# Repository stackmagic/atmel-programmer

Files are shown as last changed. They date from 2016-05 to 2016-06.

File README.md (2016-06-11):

# arduino micro as isp attiny/atmega programmer

a simple pcb with a few sockets to program attiny/atmega microcontrollers from
an arduino micro used as isp programmer

# supported atmel chips

| Microcontroller | |
|---|---|
| ATtiny 24/44/84 | http://www.atmel.com/devices/ATTINY84.aspx |
| ATtiny 25/45/85 | http://www.atmel.com/devices/ATTINY85.aspx |
| ATmega 48/88/168/328 | http://www.atmel.com/devices/ATMEGA328.aspx  |
| ATmega 164/324/644/1284 | http://www.atmel.com/devices/ATMEGA1284.aspx |

# usage

all steps below include the use of the Arduino IDE: https://www.arduino.cc/en/Main/Software (1.6 or higher).

Add the following URLs in `File > Preferences` for the setting `Additionals Boards Manager URLs`:

## ATtiny25/45/85 & ATtiny24/44/84 families:

(Supports only 45/85 & 44/84)

https://raw.githubusercontent.com/damellis/attiny/master/package_damellis_attiny_index.json

## ATmega48/88/168/328 family:

(Supports only 168/328)

https://raw.githubusercontent.com/stackmagic/atmega/master/package_carlosefr_atmega_index.json

Note: Once the PR at https://github.com/carlosefr/atmega/pull/4 is merged, use the official URL: https://raw.githubusercontent.com/carlosefr/atmega/master/package_carlosefr_atmega_index.json)

## ATmega164/324/644/1284 family:

https://mcudude.github.io/MightyCore/package_MCUdude_MightyCore_index.json

If you want to program a `Non-P` version (for example an `ATmega1284` instead of an `ATmega1284p`), you need to open your avrdude.conf and add a Section like below. The non-P versions are essentially the same as the P versions and they can be cloned. The plain 644 is supported out of the box (with avrdude 6.0.1).

```
#------------------------------------------------------------
# ATmega1284
#------------------------------------------------------------

part parent "atmega1284p"
    id               = "m1284";
    desc             = "ATmega1284";
    signature        = 0x1e 0x97 0x06;
  ;

#------------------------------------------------------------
# ATmega324
#------------------------------------------------------------

part parent "m324p"
    id               = "m324";
    desc             = "ATmega324";
    signature        = ???????????????????????;
  ;

#------------------------------------------------------------
# ATmega164
#------------------------------------------------------------

part parent "m164p"
    id               = "m164";
    desc             = "ATmega164";
    signature        = ?????????????????????????
  ;
```

## prepare the programmer

* plug in your arduino micro and connect it to the pc
* start up the arduino IDE
* connect your arduino micro
* open up the programmer sketch: `File > Examples > ArduinoISP`
* change the line `#define RESET SS` to `#define RESET 10`
* select `Tools > Board > Arduino Micro`
* burn the programmer to your Arduino Micro with `File > Upload`
* verify the RDY led is pulsing
* select your micro as programmer `Tools > Programmer > Arduino as ISP`

once this is done, you can program as many chips as you want

## burn it

* plug in the chip to program (make sure there's just 1 chip on the board ;))
* open the sketch to program to the chip
* select the correct target board through `Tools > Board > ...`
* burn the sketch using `File > Upload using Programmer`
* the PRG led should light while the program is written
* you're done!

# kicad screenshots

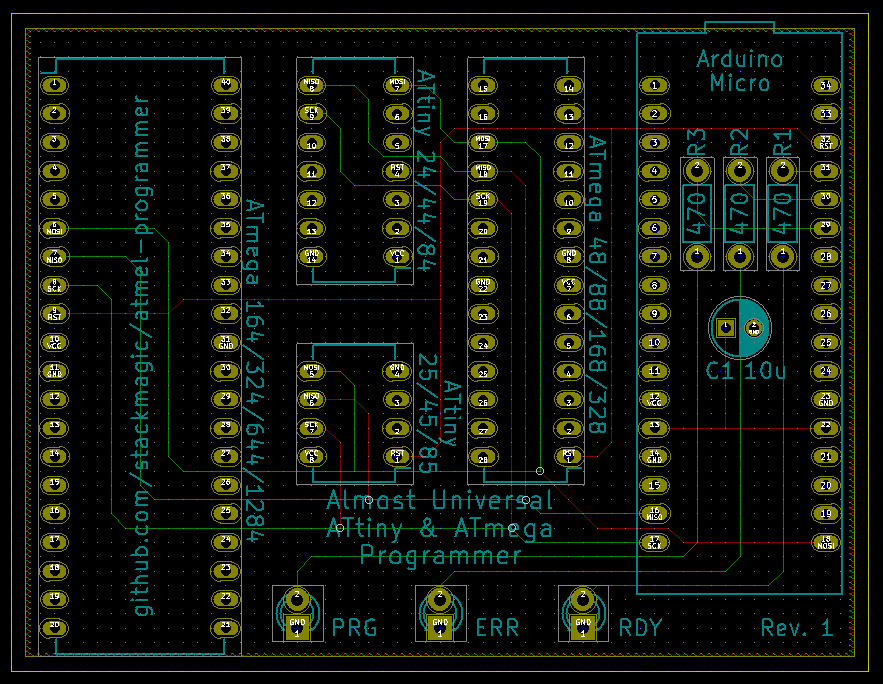
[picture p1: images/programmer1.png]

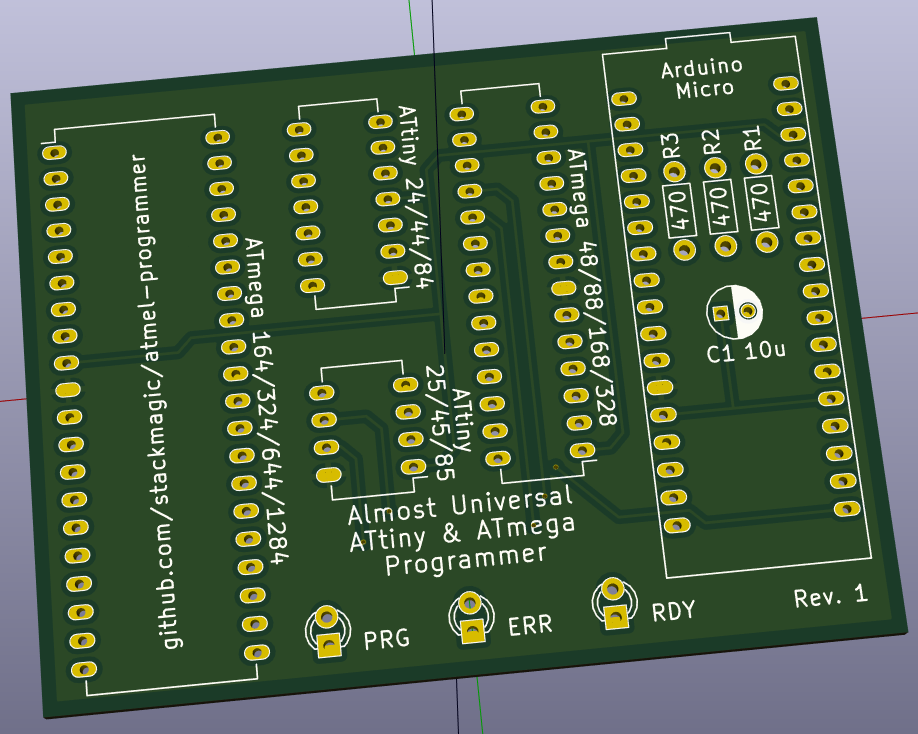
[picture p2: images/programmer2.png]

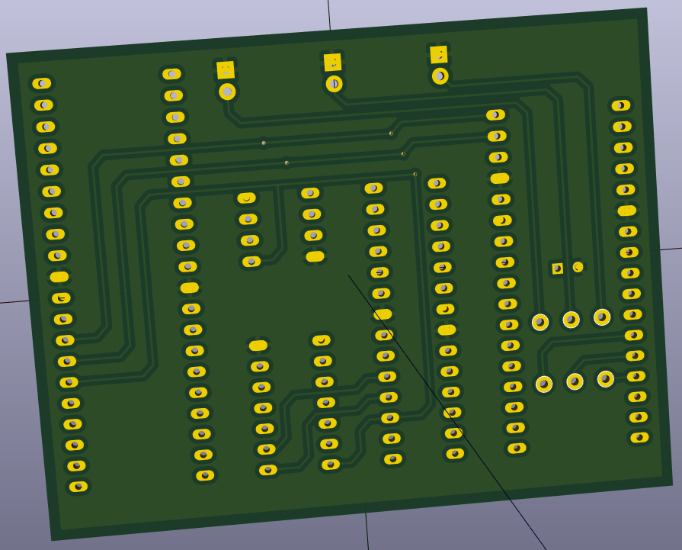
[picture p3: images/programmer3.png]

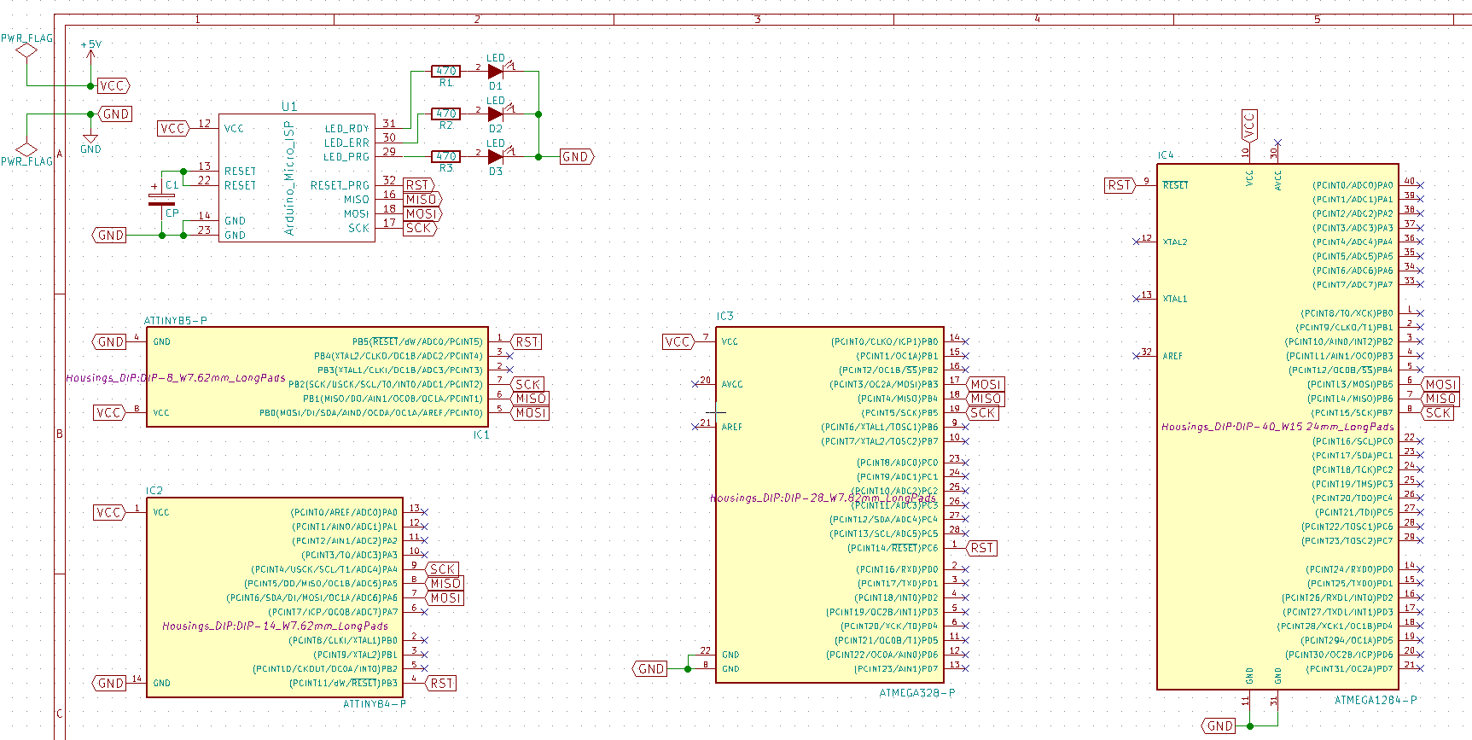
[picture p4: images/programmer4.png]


# oshpark rendering

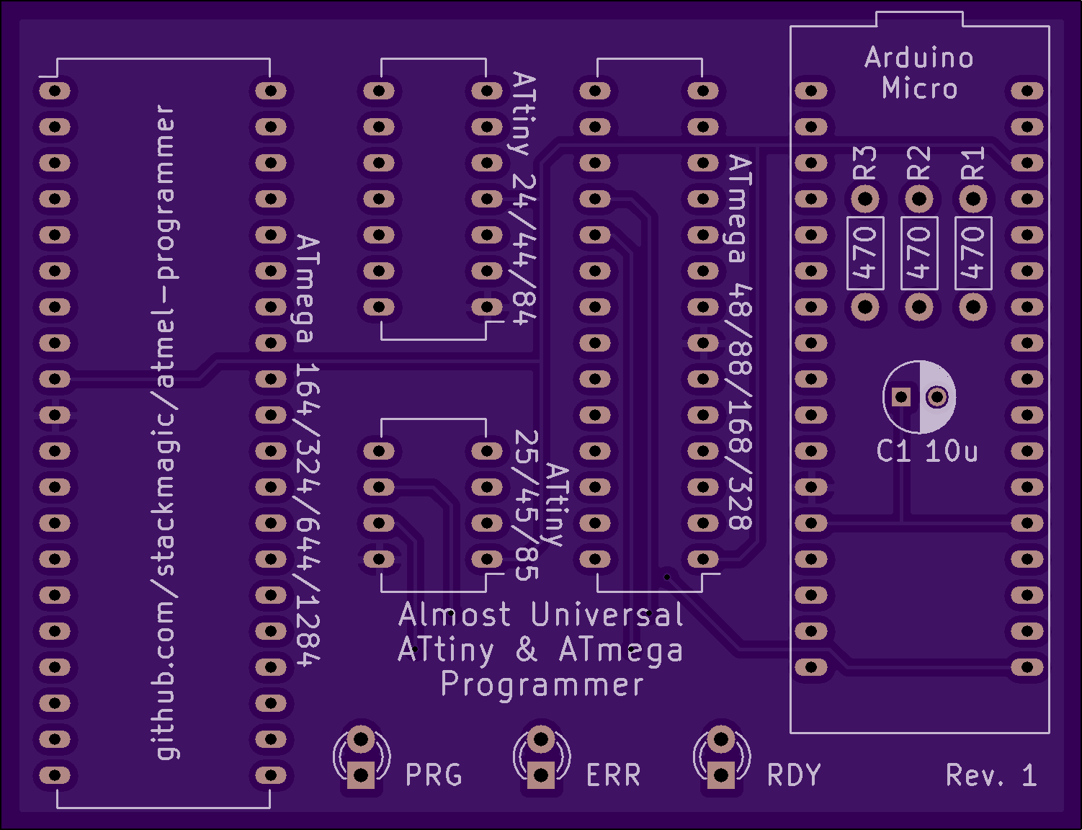
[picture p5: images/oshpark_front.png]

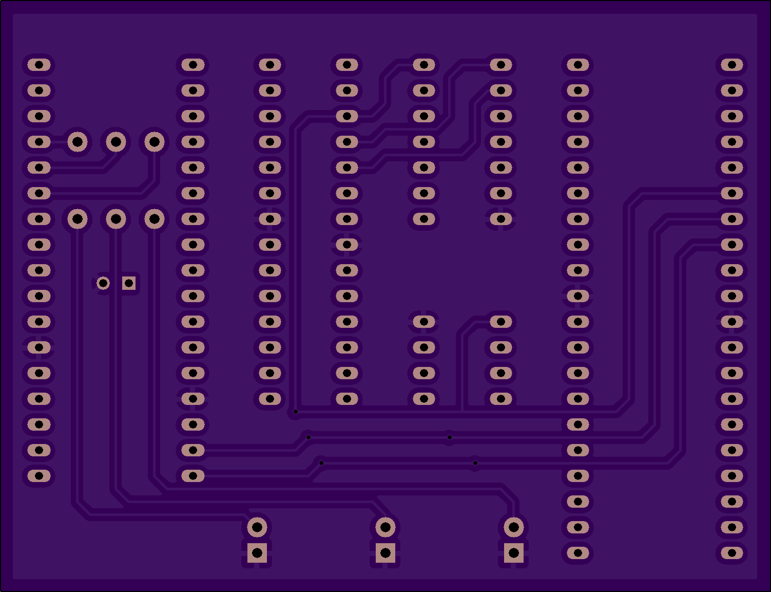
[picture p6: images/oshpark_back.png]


# further reading

## arduino micro ISP

* http://forum.arduino.cc/index.php?topic=156863.15
* http://www.arduino.cc/en/uploads/Main/arduino-micro-schematic.pdf
* https://camo.githubusercontent.com/87e06ff5c55ebb9498f5a3f7f232796a69259489/68747470733a2f2f7261776769746875622e636f6d2f426f756e692f41726475696e6f2d50696e6f75742f6d6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

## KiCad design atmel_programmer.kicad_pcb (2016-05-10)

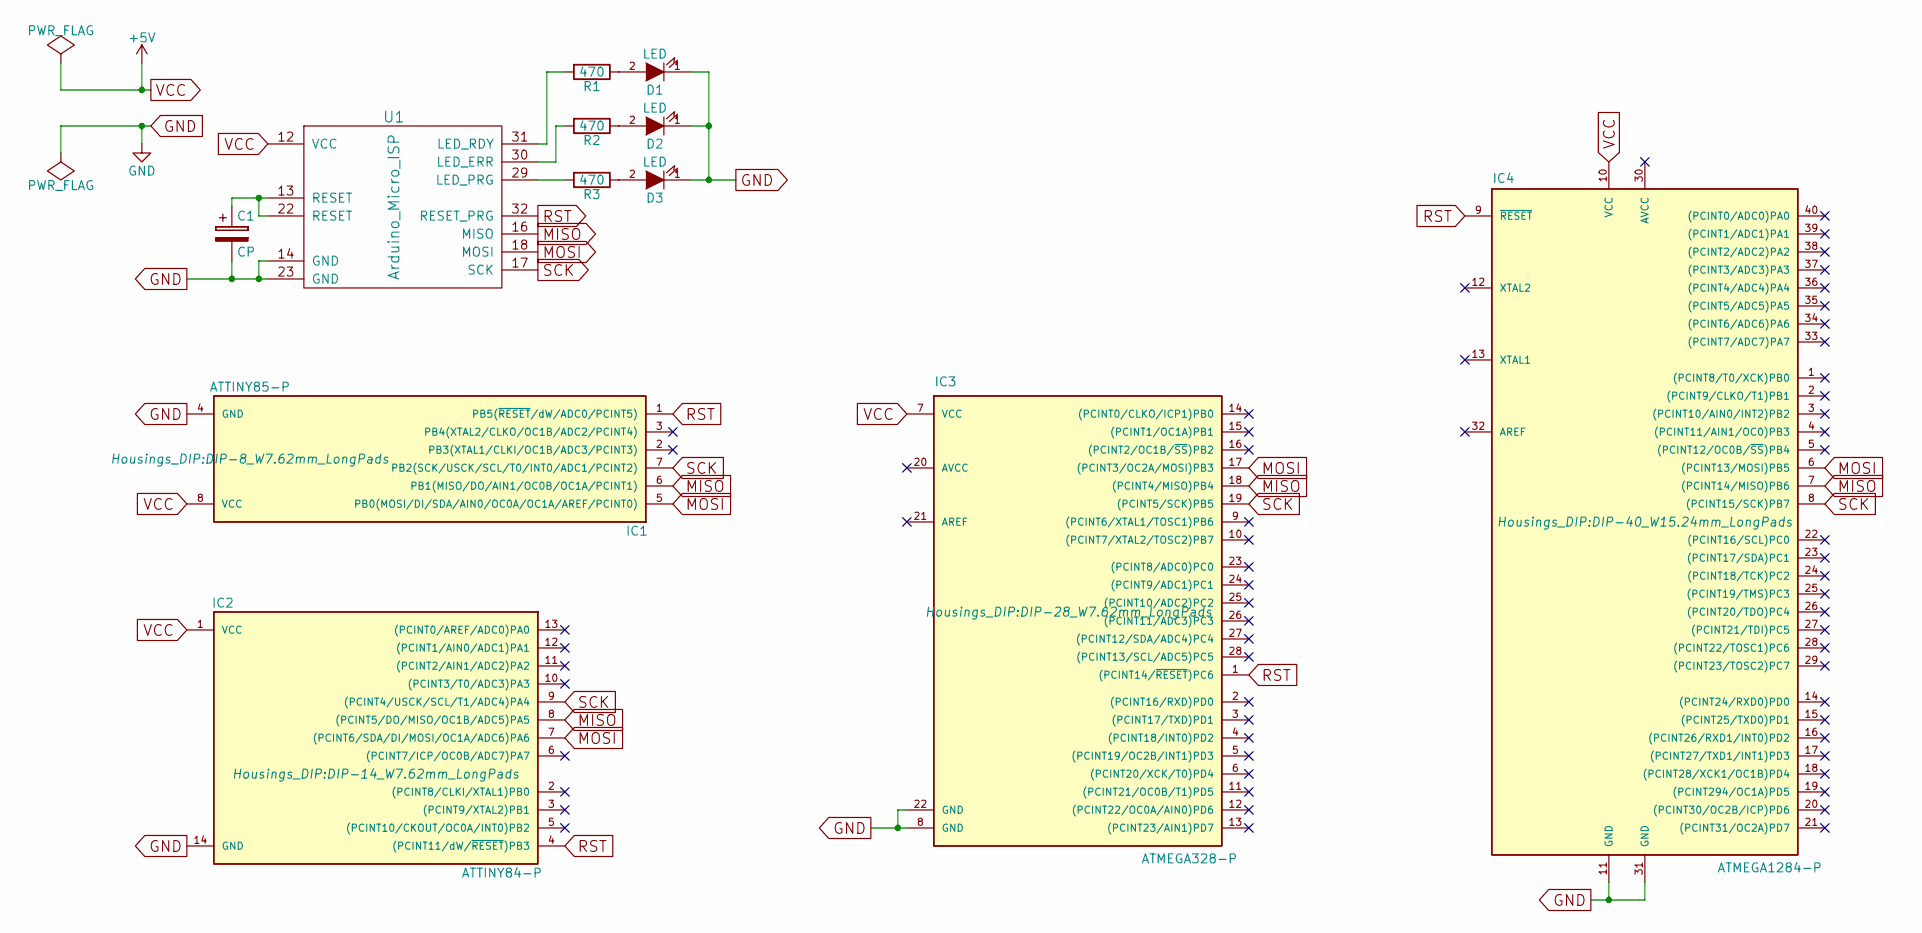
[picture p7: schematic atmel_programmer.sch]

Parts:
C1: CP; C_Radial_D5_L6_P2.5
D1, D2, D3: LED; LED-3MM
IC1: ATTINY85-P; DIP-8_W7.62mm_LongPads
IC2: ATTINY84-P; DIP-14_W7.62mm_LongPads
IC3: ATMEGA328-P; DIP-28_W7.62mm_LongPads
IC4: ATMEGA1284-P; DIP-40_W15.24mm_LongPads
R1, R2, R3: 470; Resistor_Horizontal_RM7mm
U1: Arduino_Micro_ISP; ArduinoMicro

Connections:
GND: C1.2, D1.1 (K), D2.1 (K), D3.1 (K), IC1.4 (GND), IC2.14 (GND), IC3.8 (GND), IC3.22 (GND), IC4.11 (GND), IC4.31 (GND), U1.14 (GND), U1.23 (GND)
MISO: IC1.6 (PB1(MISO/DO/AIN1/OC0B/OC1A/PCINT1)), IC2.8 ((PCINT5/DO/MISO/OC1B/ADC5)PA5), IC3.18 ((PCINT4/MISO)PB4), IC4.7 ((PCINT14/MISO)PB6), U1.16 (MISO)
MOSI: IC1.5 (PB0(MOSI/DI/SDA/AIN0/OC0A/OC1A/AREF/PCI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), IC2.7 ((PCINT6/SDA/DI/MOSI/OC1A/ADC6)PA6), IC3.17 ((PCINT3/OC2A/MOSI)PB3), IC4.6 ((PCINT13/MOSI)PB5), U1.18 (MOSI)
unnamed: C1.1, U1.13 (RESET), U1.22 (RESET)
unnamed: D1.2 (A), R1.1
unnamed: D2.2 (A), R2.1
unnamed: D3.2 (A), R3.1
unnamed: R1.2, U1.31 (LED_RDY)
unnamed: R2.2, U1.30 (LED_ERR)
unnamed: R3.2, U1.29 (LED_PRG)
RST: IC1.1 (PB5(~RESET~/dW/ADC0/PCINT5)), IC2.4 ((PCINT11/dW/~RESET~)PB3), IC3.1 ((PCINT14/~RESET~)PC6), IC4.9 (~RESET), U1.32 (RESET_PRG)
SCK: IC1.7 (PB2(SCK/USCK/SCL/T0/INT0/ADC1/PCINT2)), IC2.9 ((PCINT4/USCK/SCL/T1/ADC4)PA4), IC3.19 ((PCINT5/SCK)PB5), IC4.8 ((PCINT15/SCK)PB7), U1.17 (SCK)
VCC: IC1.8 (VCC), IC2.1 (VCC), IC3.7 (VCC), IC4.10 (VCC), U1.12 (VCC)

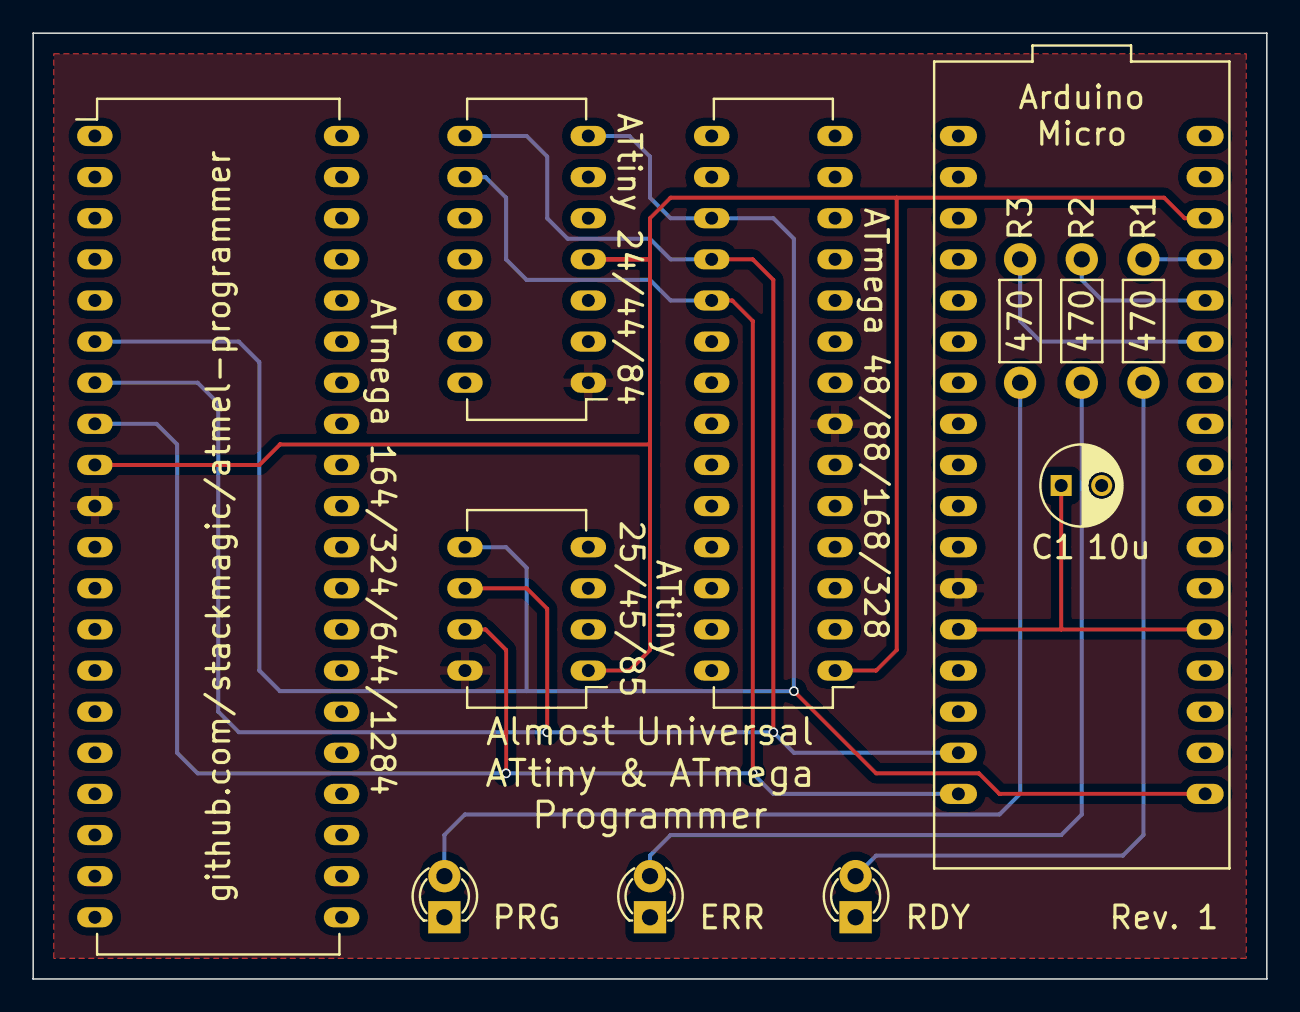
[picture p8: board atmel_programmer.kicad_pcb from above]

Board: 2 copper layers, 76.2 x 58.4 mm, 12 parts (0 on the bottom side), 13 nets.

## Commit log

2016-05-10 initial files
    [atmel_programmer-B.Cu.gbr, atmel_programmer-B.Mask.gbr, atmel_programmer-B.SilkS.gbr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]
2016-05-11 some screenshots of the board
2016-05-12 readme: links to atmel.com, arduino.cc
